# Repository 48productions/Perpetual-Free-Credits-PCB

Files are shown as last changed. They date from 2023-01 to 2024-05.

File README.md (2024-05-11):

# Perpetual Free Credits PCB (a.k.a. the PFC PCB)
**A Non-Destructive Arcade Game Coinup Mod PCB**

It keeps compatible games fully credited up at all times, perfect for arcade games that either lack a Free Play mode, or are missing features in Free Play mode that are present in Credit mode.

It's designed solely for games with a **credit limit** that control a **coin blocker** relay based on this limit. If the game isn't at its credit limit, it powers the coin blocker relay (and thus the PFC PCB), which inserts credits until the credit limit is reached, and the game turns off the coin blocker relay. 

---
## Compatibility/Installation

### Compatibility List
This board is **compatible** with:
 - ✅ CHUNITHM (tested on NEW!! and many pre-NEW!! versions)
 - ✅ Middle Earth (Atari pinball)
 - ✅ crossbeats REV. (tested on SUNRISE S2)*
 - ✅ Probably a lot of others :D

This board is **incompatible** with games that have a coin blocker relay, but no credit limit:
 - ❌ SOUND VOLTEX (tested on EXCEED GEAR)
 - ❌ jubeat (tested on festo)

An alternative design is being considered for these games.

*\* crossbeats: This board will continuously insert credits in test mode, since the game always powers the coin blocker in test mode regardless of the credit limit.*

### Checking Compatibility
**For games not on the list, your game MUST:**

 - **Have a coin blocker relay** on the coin acceptor (mostly found in older or JP-import games)
 
 - Power said relay with *10-30VDC* or *5VDC*
 
 - Turn on the relay when the game enters attract mode (you'll hear it click on)
 
 - **Have a credit limit, and will turn off the Coin Blocker when this limit is reached** (this is not always the case)!

In modern games, the relay can usually be toggled on/off in the game's test mode (look for an "Output Test" menu).

---
## Alternative Designs
[ChunUp](https://github.com/progmem/ChunUp) is a very clean and cost-reduced design geared specifically for CHUNITHM cabinets.

---
## Fabrication
**[See FABRICATION.md](FABRICATION.md) for instructions on how to fabricate this design!**

---
## Installation
**[See INSTALLATION.md](INSTALLATION.md) for instructions on how to install this board in your game!**

---
## Troubleshooting
**[See TROUBLESHOOTING.md](TROUBLESHOOTING.md) for instructions on how to troubleshoot common issues!**

---
## No Really How Does This Work

This board connects to the power wires for the Coin Blocker relay on your arcade cabinet, if it has one, through voltage regulator U2. Normally, this relay is attached to the game's coin acceptor and will reject any coins (even valid ones) whenever the game is not ready to accept coins (game powered off, maximum credit limit reached, etc).

When the game is ready to accept coins, it powers the coin blocker to let coins in. This turns on the PFC board, which will repeatedly trigger the game's coin switch using timer U1 through opto isolator U3. When the game hits the maximum credit limit, it powers off the coin relay (and thus the PFC board), which stops inserting coins. This way, your game is always credited up and ready to play.

Timing of the pulses is controlled by capacitor C1, resistor R2 (20k, time between pulses), and resistor/potentiometer R1/VR1 (1k + 0-10k, pulse frequency).

---
## Credits/Disclaimers

This project came about because of a few relevant conversations in the awesome western arcade rhythm game community, and the general concept/design was discussed by several community members.

You are installing this board at your own risk, and I cannot be held liable for damages, destruction, magic smoke escaping, or otherwise.

For arcade games on an official online network, your network may not allow the use of this board or similar mods. As such, usage of this board in these circumstances isn't recommended.

*Any games mentioned are properties of their respective owners. This design was produced independently of them, and is in no way endorsed or officially supported.*

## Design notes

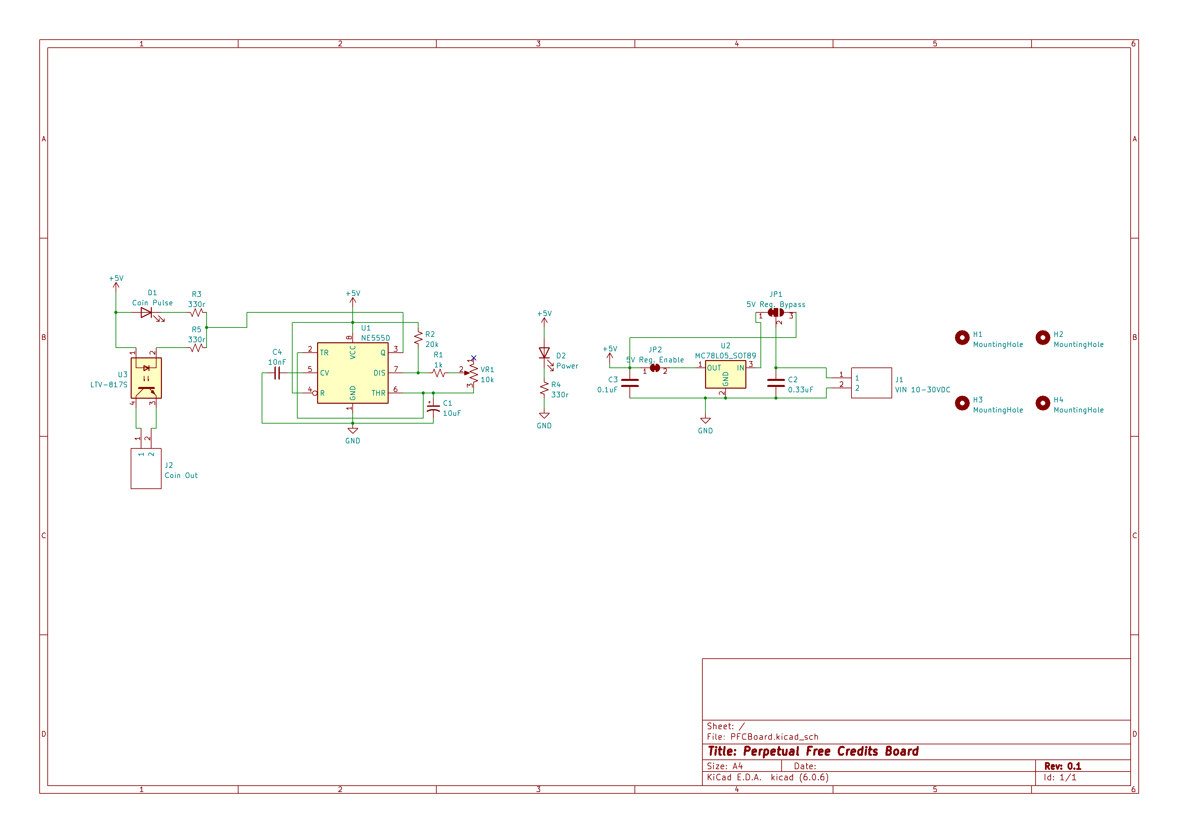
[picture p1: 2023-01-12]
Schematic.png

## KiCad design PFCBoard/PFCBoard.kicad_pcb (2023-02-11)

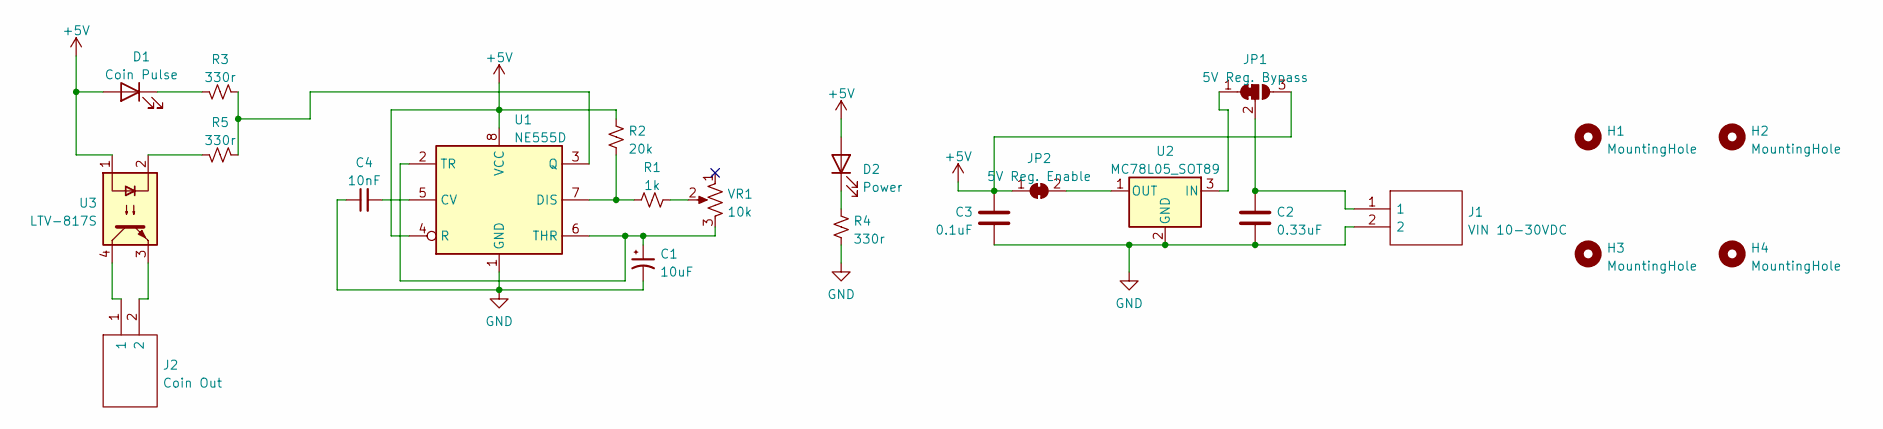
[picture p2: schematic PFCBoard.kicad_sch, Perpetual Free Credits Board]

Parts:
C1: 10uF; CP_Elec_4x4.5
C2: 0.33uF; C_1206_3216Metric_Pad1.33x1.80mm_HandSolder
C3: 0.1uF; C_1206_3216Metric_Pad1.33x1.80mm_HandSolder
C4: 10nF; C_1206_3216Metric_Pad1.33x1.80mm_HandSolder
D1: Coin Pulse; LED_1206_3216Metric_Pad1.42x1.75mm_HandSolder
D2: Power; LED_1206_3216Metric_Pad1.42x1.75mm_HandSolder
H1, H2, H3, H4: MountingHole; MountingHole_3mm
J1: VIN 10-30VDC; 1713017; Manufacturer_Part_Number 1713017; Mouser Part Number 651-1713017
J2: Coin Out; 1713017; Manufacturer_Part_Number 1713017; Mouser Part Number 651-1713017
JP1: 5V Reg. Bypass; SolderJumper-3_P1.3mm_Bridged12_Pad1.0x1.5mm
JP2: 5V Reg. Enable; SolderJumper-2_P1.3mm_Bridged_Pad1.0x1.5mm
R1: 1k; R_1206_3216Metric_Pad1.30x1.75mm_HandSolder
R2: 20k; R_1206_3216Metric_Pad1.30x1.75mm_HandSolder
R3, R4, R5: 330r; R_1206_3216Metric_Pad1.30x1.75mm_HandSolder
U1: NE555D; SOIC-8_3.9x4.9mm_P1.27mm
U2: MC78L05_SOT89; SOT-89-3
U3: LTV-817S; SMDIP-4_W9.53mm
VR1: 10k; Potentiometer_Bourns_TC33X_Vertical

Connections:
+5V: C3.1, D1.2 (A), D2.2 (A), JP1.3 (B), JP2.1 (A), R2.1, U1.4 (R), U1.8 (VCC), U3.1
GND: C1.2, C2.2, C3.2, C4.1, J1.2, R4.2, U1.1 (GND), U2.2 (GND)
unnamed: C1.1, U1.2 (TR), U1.6 (THR), VR1.3
unnamed: C2.1, J1.1, JP1.2 (C)
unnamed: C4.2, U1.5 (CV)
unnamed: D1.1 (K), R3.2
unnamed: D2.1 (K), R4.1
unnamed: J2.1, U3.4
unnamed: J2.2, U3.3
unnamed: JP1.1 (A), U2.3 (IN)
unnamed: JP2.2 (B), U2.1 (OUT)
unnamed: R1.1, R2.2, U1.7 (DIS)
unnamed: R1.2, VR1.2
unnamed: R3.1, R5.1, U1.3 (Q)
unnamed: R5.2, U3.2

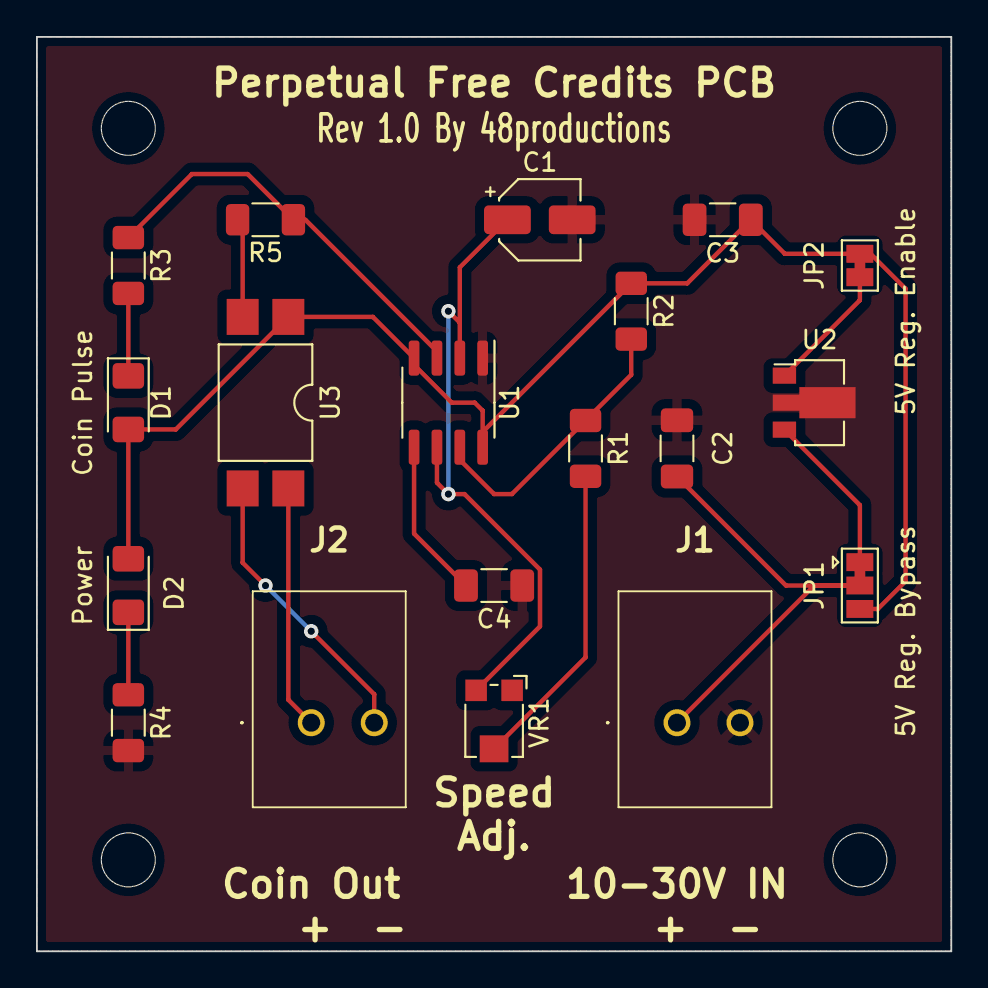
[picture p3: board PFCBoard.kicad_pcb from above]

Board: 2 copper layers, 50.8 x 50.8 mm, 23 parts (0 on the bottom side), 15 nets.

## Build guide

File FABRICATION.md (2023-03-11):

# Fabrication
The PFCBoard is an open-source board design - though I (at least currently) do not sell pre-made boards with this design, it's not too challenging to make your own!

All components use large footprints to make hand-soldering fairly straightforward.

## Ordering the PCBs
First, you'll need the blank PCBs - these can be obtained through a service like OSHPark, PCBWay, JLCPCB, etc.

How this is done depends on the board manufacturer, but is usually done by uploading a .zip file containing the board design in the Gerber file format. Some services can take the KiCad project files directly.

[You can find pre-made Gerber files in the Releases](https://github.com/48productions/Perpetual-Free-Credits-PCB/releases) section of this repo, but keep in mind **different board houses may have different requirements for the board design and file format.** Your best bet is to check their site for details, and re-export a new set of Gerbers from KiCad if needed.

## Ordering the Components
PFCBoard v1.0 uses the following components. Connectors aside, all components are SMD. I'll link components I've personally used, here.
 - U1: [555 timer IC, 8-SOIC](https://www.digikey.com/en/products/detail/texas-instruments/SA555DR/555957)
 - U3: [LTV-817S Optoisolator](https://www.digikey.com/en/products/detail/liteon/LTV-817S/385837)
 - C1: [10uF Capacitor, 4mmx4.5mm](https://www.digikey.com/en/products/detail/nichicon/UWJ1C100MCL1GB/2550755)
 - C3: [0.1uF Capacitor, 1206](https://www.digikey.com/en/products/detail/kemet/C1206C104K5RAC7800/411248)
 - C4: [10nF Capacitor, 1206](https://www.digikey.com/en/products/detail/samsung-electro-mechanics/CL31B103KHFNFNE/3888735)
 - D1-2: [Yellow](https://www.digikey.com/en/products/detail/w%C3%BCrth-elektronik/150120YS75000/4489948), [Red](https://www.digikey.com/en/products/detail/w%C3%BCrth-elektronik/150120RS75000/4489939) LED, ~2V/20mA max, 1206
 - J1-2: [1713017 Terminal Block](https://www.digikey.com/en/products/detail/phoenix-contact/1713017/2513977)
 - R1: [1k Resistor, 1206](https://www.digikey.com/en/products/detail/stackpole-electronics-inc/RMCF1206FT1K00/1759616)
 - R2: [20k Resistor, 1206](https://www.digikey.com/en/products/detail/stackpole-electronics-inc/RMCF1206FT20K0/1759766)
 - R3-5: [330r Resistor, 1206](https://www.digikey.com/en/products/detail/stackpole-electronics-inc/RMCF1206JT330R/1753819)
 - VR1: [TC33X-2-103E 10k Potentiometer](https://www.digikey.com/en/products/detail/bourns-inc/TC33X-2-103E/612858)

The following can be left unpopulated if the 5V regulator will be bypassed for a 5V coin blocker:
 - U2: [MC78L05FA-TP 5V Regulator, SOT-89](https://www.digikey.com/en/products/detail/micro-commercial-co/MC78L05FA-TP/13689757)
 - C2: [0.33uF Capacitor, 1206](https://www.digikey.com/en/products/detail/samsung-electro-mechanics/CL31B334KBFNNNE/3886796)

And if you're feeling really extra:
 - Board Standoffs for a 3mm hole (such as [Digikey #732-9624-ND](https://www.digikey.com/en/products/detail/w%C3%BCrth-elektronik/702915000/5843784))

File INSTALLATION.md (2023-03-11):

# Installation (10V-30V Coin Blocker)
 1) Identify the positive and negative wires that power the coin blocker, using either a multimeter or the game's schematics.
 
 2) Power off the game and disconnect the coin blocker. Connect the coin blocker wires to the power input terminals on the PFC board.
   - Connect positive to the red power terminal on the board, negative to white. __Reversing the two may damage the PFC board.__
 3) Attach the wires going to the coin switch itself to the "Coin Out" terminals on the PFC board.
 
   - Like the coin blocker, connect negative (usually black) to white, positive to red. Reversing the two shouldn't damage anything, but the board will not function.

# Installation (5V Coin Blocker Mod)
If your game uses a 5V coin blocker relay (do these even exist?), you must bypass the on-board voltage regulator.

1) Cut the "5V Reg Bypass" and "5V Reg Enable" jumpers on the right side of the board with an x-acto knife. Check that the two pads of each jumper have NO continuity with a multimeter.

2) Bridge the bottom two pads of the "5V Reg Bypass" jumper with solder, leaving the top pad disconnected.

With these mods, the PFC board will *only* accept 5V power input and can be installed using the above steps. __Higher voltages will damage the PFC Board__.
To revert this mod, reverse these steps.

# Speed Adjustment
Turn the dial between the Power and Coin terminals with a small screwdriver to adjust the rate that the PFC board inserts coins at.

This is mostly up to personal preference, but may help with troubleshooting game-specific compatiblity.

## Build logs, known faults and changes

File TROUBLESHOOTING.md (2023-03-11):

# PFC Board Troubleshooting
Two LEDs are on the board to assist with troubleshooting.

## Power LED never lights, game does not coin up
Check the power connections to the PFC board. Ensure they are NOT reversed.

Ensure the game's coin blocker output is working (via multimeter or by re-connecting the coin blocker relay), and that the voltage it outputs is in the right voltage range for the PFC board. 5V coin blockers require the modification described in FABRICATION.md.

## Power LED lights and coin LED blinks, but coins do not insert.
Check the coin connections to the PFC board. Try swapping the two coin wires around.

Some games may not accept coins when in test mode, regardless of the coin blocker state.

## PFC board keeps inserting coins even if the game isn't fully booted/after the credit limit is reached
Check that the PFC board is connected to the coin blocker signal and not to wires that are always receiving power (like for a lamp, coin acceptor power, etc).

Some games continue to power the coin blocker accept coins, even when the credit display maxes out "99" coins. These games are incompatible with the Perpetual Free Credits board.

Some games may power the coin blocker and not accept coins in test mode, keeping the board powered and inserting coins.

## Power LED on, Coin LED either stays lit or never lights
The PFC board's timing circuit is not working. If adjusting the speed adjustment dial does not fix this, the PFC board must be repaired.

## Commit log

2022-12-26 Schematic Rev v0.1
    [PFCBoard.kicad_sch]
2022-12-31 Add voltage selection, pre-rendered schematic
    [PFCBoard.kicad_sch]
2023-01-12 PCB design, schematic/readme tweaks
    [PFCBoard.kicad_pcb, PFCBoard.kicad_sch]
2023-02-11 PFCBoard v1 Gerbers
    [PFCBoard-B_Cu.gbl, PFCBoard-B_Mask.gbs, PFCBoard-B_Silkscreen.gbo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]
